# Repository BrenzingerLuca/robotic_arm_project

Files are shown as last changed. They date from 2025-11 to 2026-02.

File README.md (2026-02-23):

# PI-Bot: Distributed 3-DOF Robotic Arm

## Table of Contents
1. [Project Overview & Demo](#1-project-overview--demo)
2. [System Architecture](#2-system-architecture)
3. [Key Features](#3-key-features)
4. [PI-Bot control center (GUI)](#4-gui)
5. [Digital Twin](#5-digital-twin)
6. [Hardware & Wiring](#6-hardware--wiring)
7. [Quick start](#7-quick--start)
8. [Challenges & Solutions](#8-challenges)

## Project Structure 

```text
robotic_arm_project/
├── docs/           
├── src/   
├──── move_it_services/         # Custom Srv/Msg definitions (e.g. MoveToXYZ)
├──── my_robot_interfaces/      # Custom interfaces used in multiple nodes
├──── pca9685_servo_controller/ # Control the physical servos 
├──── potentiometer_reader/     # Read out potentiometer values
├──── robot_controller/         # MoveIt2 controller config
├──── robot_description/        # URDF & meshes
├──── robot_fk/                 # Forward kinematic calculations
├──── robot_gui/                # Pibot GUI
├──── robot_moveit/             # MoveIt2 configuration & SRDF
└── README.md                   # Documentation
```

## 1. Project Overview & Demo 
<p align="center">
  Projekt Demo
</p>

### About the Project
The **PI-Bot** is a custom-engineered, 3D printed, 3-DOF robotic arm designed as a full-stack robotics project. It demonstrates the seamless integration of distributed software systems, real-time hardware interaction, and motion planning. 

**Core Motivation & Software Focus**
The primary goal of this project was to master the software stack, specifically to understand **MoveIt** and motion planning architectures from the ground up. To bridge the gap between theory and reality, I implemented the system using 3D-printed parts and budget-friendly servos. 

While this accessible hardware introduces some mechanical imprecision, it served its purpose as a verification platform for the software. Future iterations will focus on hardware refinement to improve physical accuracy, though the core of this project remains a deep dive into robotics software engineering.

The project covers:
*   **Mechanical Design in CAD:** 3-axis manipulator with gripper.
*   **Embedded Control:** Custom ROS2 nodes on a Raspberry Pi 4 for PWM actuation and ADC sensor readout.
*   **Advanced Middleware:** MoveIt2 for path planning and a synchronized Digital Twin.
*   **UI:** A PySide6/Qt GUI for orchestration.

---

## 2. System Architecture 

The PI-Bot is built on a **distributed ROS2 architecture**, separating high-level logic from hardware-near execution to ensure modularity and system stability.

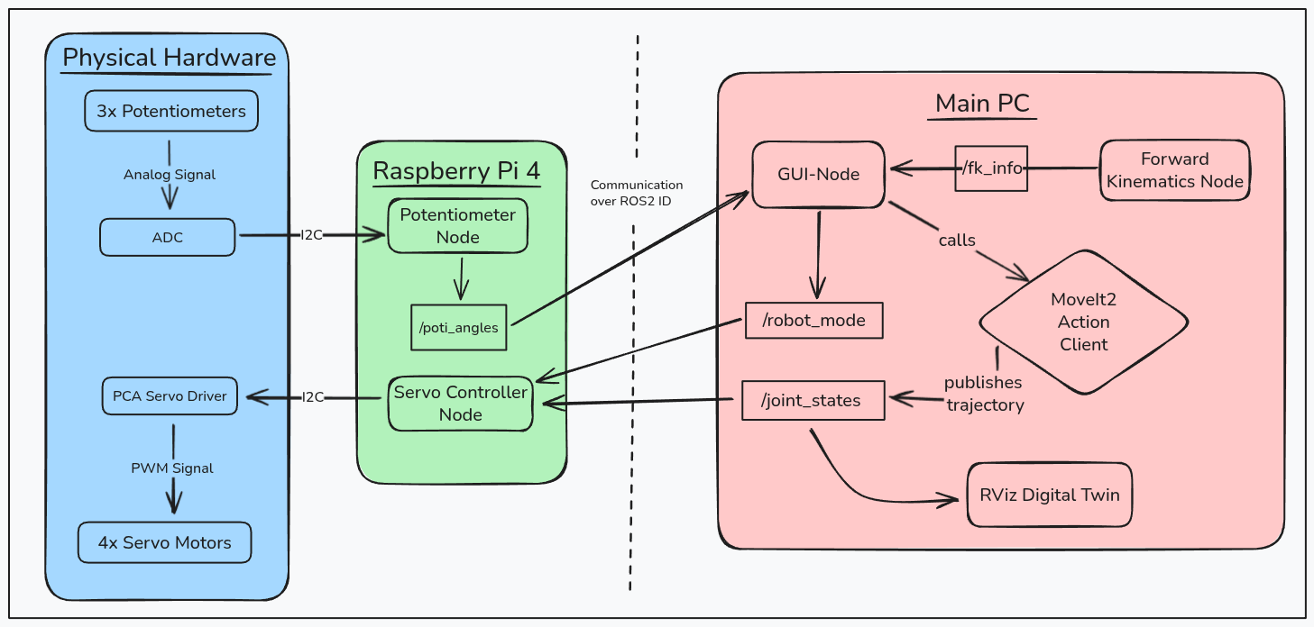
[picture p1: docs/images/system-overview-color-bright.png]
System Overview

*Figure: High-level overview of the distributed control loop and node communication.*

### Main PC (High-Level Logic)
The workstation acts as the "Brain" of the system, running computationally intensive nodes:
*   **GUI-Node (PySide6):** The central hub for user interaction. It subscribes to `/poti_angles` for manual input and `/fk_info` for real-time monitoring of the end-effector position. It orchestrates movements by calling the MoveIt2 Action Client and controls if the robot is in hardware or simulation mode.
*   **MoveIt2 Action Client:** Handles trajectory planning and inverse kinematics (IK). Once a path is planned, it publishes the trajectory points to the `/joint_states` topic.
*   **Forward Kinematics Node:** A dedicated node that processes joint angles to calculate the end-effector's XYZ position, providing feedback to the GUI.
*   **RViz Digital Twin:** Subscribes to `/joint_states` to provide a real-time 3D visualization of the robot's physical state.

### Raspberry Pi 4 (Hardware Abstraction Layer)
The Pi 4 serves as the bridge between the digital ROS2 environment and the physical hardware:
*   **Potentiometer Node:** Interfaces with the **ADS7830 ADC** via **I2C**. It reads analog signals from the three potentiometers, processes them, and publishes the values to the `/poti_angles` topic.
*   **Servo Controller Node:** Subscribes to the `/joint_states` and `/robot_mode` topics from the main PC and converts these states into **I2C** commands for the **PCA9685 Servo Driver**. When the robot is in hardware mode, the driver generates PWM signals to control the four servo motors.

### Communication Layer
*   **ROS2 Middleware:** All communication between the PC and the Raspberry Pi is handled over the local network using a shared **ROS_DOMAIN_ID**.
---

## 3. Key Features 

*   **Multi-Modal Hybrid Control:** The PI-Bot offers four distinct ways to interact with the hardware:
    *   **Joint-Space Control:** Precise manipulation of individual axes via interactive GUI sliders (0-180°).
    *   **Cartesian-Space Control:** Users can input target **XYZ-coordinates** (in mm). The system calls a custom `MoveToXYZ` service to plan and execute the motion.
    *   **Hardware-in-the-Loop (HIL):** Real-time physical **analog potentiometers** for intuitive manual positioning.
    *   **Interactive Planning (MoveIt2):** Full integration with RViz, allowing users to move the robot via **Drag & Drop (Interactive Markers)**. 

*   **Real-time State Sync:** The `sync_sliders_to_movement` logic continuously updates the GUI sliders to always match the actual hardware state, preventing jumps when switching control modes.
*   **Teach-In Sequence Recorder:** Store specific positions of the end-effector, or gripper in a table and execute them as a complex motion sequence.

*   **Asynchronous Processing:** Multi-threaded Python/Qt implementation to keep the UI responsive during long-running trajectory executions and service/action calls.

---
## 4. PI-Bot Control Center (GUI) 

The **PI-Bot Control Center** is a PySide6 (Qt)-based HMI providing centralized control, state monitoring, motion teaching, and direct servo manipulation via sliders.

<p align="center">
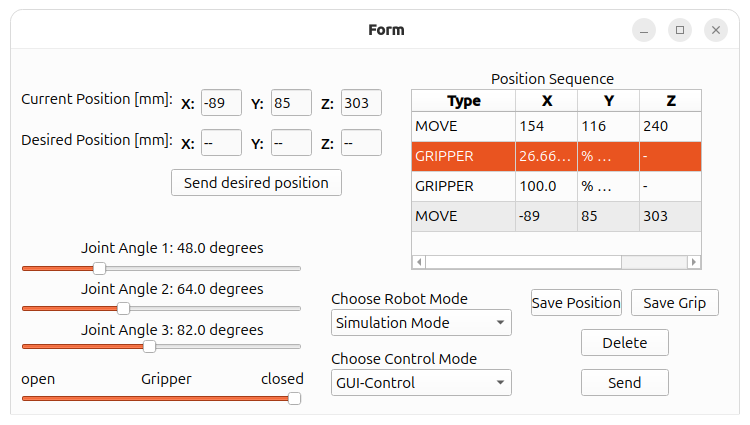
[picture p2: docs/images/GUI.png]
  
  <br>
  <em>Figure: The PI-Bot Control Center showing a programmed stacking sequence.</em>
</p>

## Core Interface Components

### Cartesian Monitoring & IK Control (Top Left)
- **Live Feedback:** Displays the end-effector’s real-time XYZ coordinates (mm), computed by the Forward Kinematics (FK) node.  
- **Target Input:** Users can enter desired Cartesian coordinates. Clicking **“Send desired position”** invokes MoveIt2 Inverse Kinematics (IK) to plan and execute the motion.

### Joint-Space Manipulation (Bottom Left)
- **Interactive Sliders:** Direct control of all three joints and the gripper.  
- **Bi-directional Sync:** Sliders continuously reflect the robot’s physical state, including movements from external potentiometers or those triggered by the “Send Desired Position” or “Sequence” functionality.

### Teach-In Panel (Right)
- **Sequence Recorder:**  
  - **“Save Position”** stores the current spatial position.  
  - **“Save Grip”** stores the current gripper state.  
- **Automation Workflow:**  
  - The table holds command types:  
    - `MOVE` → spatial target  
    - `GRIPPER` → aperture state  
- **Configuration:**  
  - Pressing **Delete** removes the currently selected (orange-highlighted) row.
- **Execution:**  
  - Pressing **“Send”** runs the sequence from top to bottom, enabling autonomous repetitive tasks (e.g., stacking or sorting).

### System Mode Management (Bottom Center)
- **Robot Mode:**  
  - **Simulation Mode** → Digital twin visualization  
  - **Hardware Mode** → Physical servo actuation  
- **Control Mode:**  
  - **GUI Control**  
  - **Potentiometer Control (Hardware-in-the-Loop)**
---
## 5. Digital Twin 

A core feature of the PI-Bot is the implementation of a **Digital Twin**. This virtual mirror ensures that every movement of the physical hardware is precisely reflected in the simulation environment (RViz) and vice versa.

<p align="center">
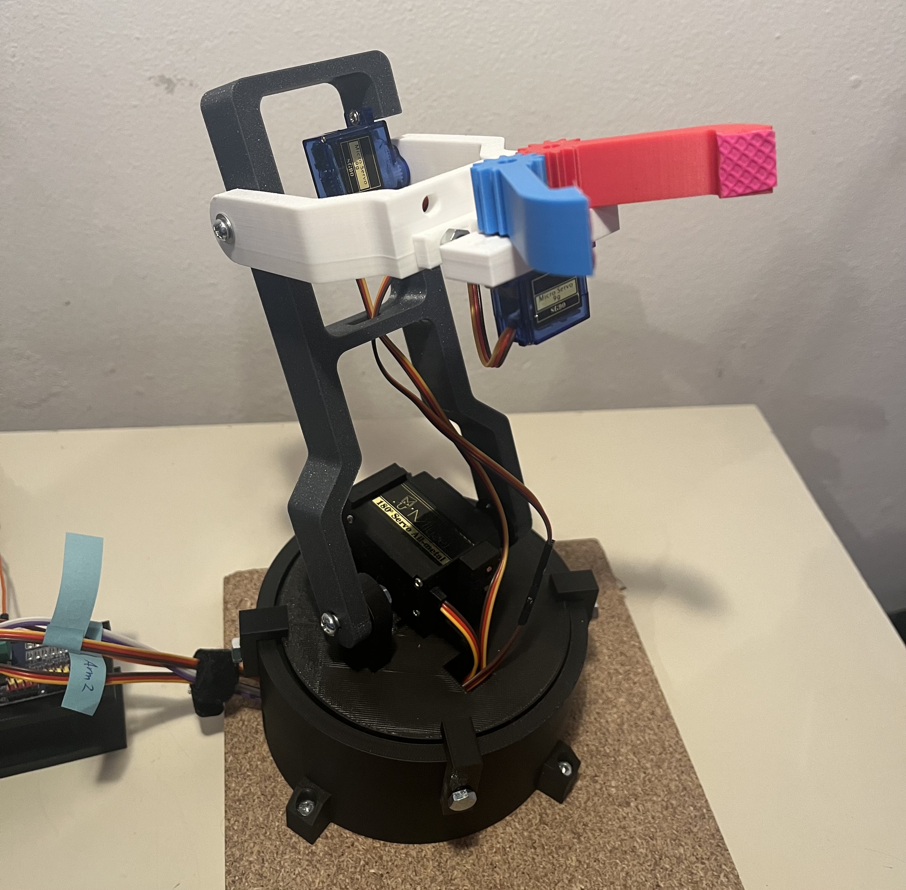
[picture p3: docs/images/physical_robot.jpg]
Physical PI-Bot
  
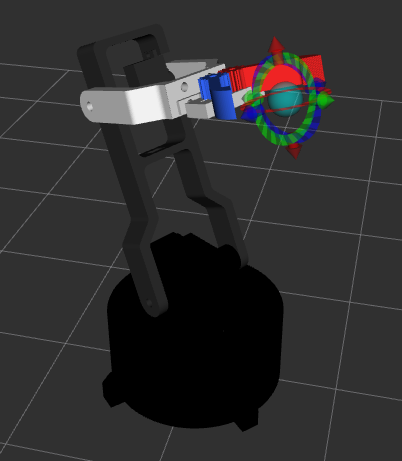
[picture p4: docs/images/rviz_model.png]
Digital Twin in RViz
  
  <br>
  <em>Figure: Comparison between the physical 3-DOF arm (left) and its synchronized Digital Twin in RViz (right).</em>
</p>

<p align="center">
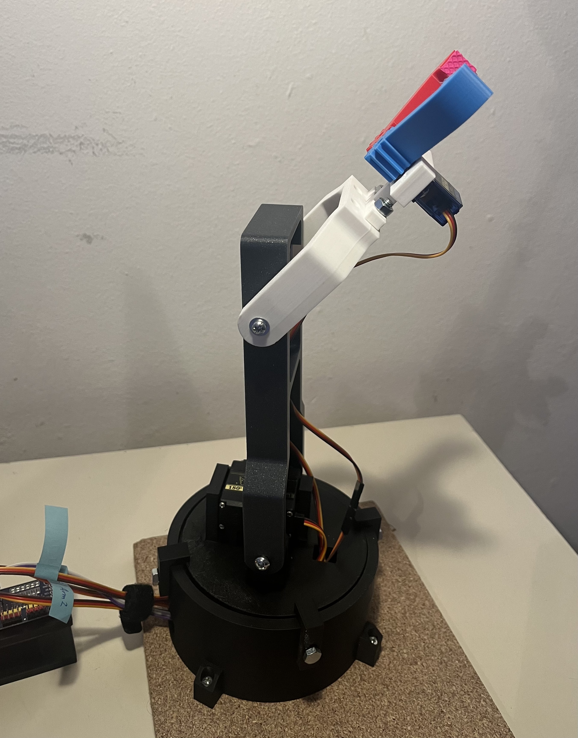
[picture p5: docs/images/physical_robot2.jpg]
Physical PI-Bot
  
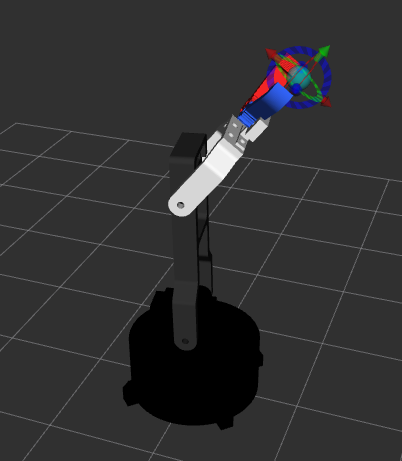
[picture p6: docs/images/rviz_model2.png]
Digital Twin in RViz
  
  <br>
  <em>Figure: Comparison between the physical 3-DOF arm (left) and its synchronized Digital Twin in RViz (right).</em>
</p>

### Physical-to-Digital Synchronization

*   **URDF & Mesh Integration:** The robot is defined via a custom **Unified Robot Description Format (URDF)**, using precise meshes from my own CAD Design and joint limits derived from the Moveit config.
*   **State Mirroring:** By subscribing to the `/joint_states` topic, the `robot_state_publisher` updates the **TF-tree** in real-time.
*   **Safety & Planning:** Before any physical movement occurs, MoveIt2 uses the Digital Twin to perform **collision checking** and trajectory validation, ensuring safe operation in the physical workspace.
*   **Remote Monitoring:** Through the distributed architecture, the Digital Twin allows for full remote monitoring of the robot's status over the network without needing a direct line of sight to the hardware.
---
## 6. Hardware & Wiring 

### Used Components:
| Component | Quantity | Interface | Description |
| :--- | :---: | :--- | :--- |
| **Raspberry Pi 4 (4GB)** | 1 | Network/I2C | Main distributed controller node |
| **ADS7830 ADC** | 1 | I2C (0x48) | 8-channel 8-bit ADC for potentiometer readout |
| **PCA9685 Driver** | 1 | I2C (0x40) | 16-channel PWM controller for servos |
| **MZ996 Servos** | 2 | PWM | High-torque servos for the base and the first arm|
| **9G Micro Servo** | 2 | PWM | Lightweight servo for the gripper mechanism and upper arm|
| **Potentiometers** | 3 | Analog | 10k Ohm linear potentiometers for HIL control |
| **Power Supply** | 1 | DC | External 5V/10A supply for Servo Driver |

### Wiring Diagram

<p align="center">
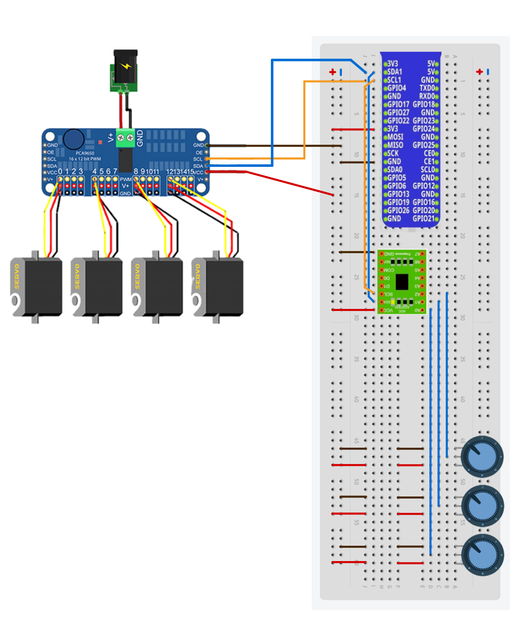
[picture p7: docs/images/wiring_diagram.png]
Visual Wiring Diagram
  
  <br>
  <em>Figure: Visual wiring overview.</em>
</p>

### Real-Life Implementation

<p align="center">
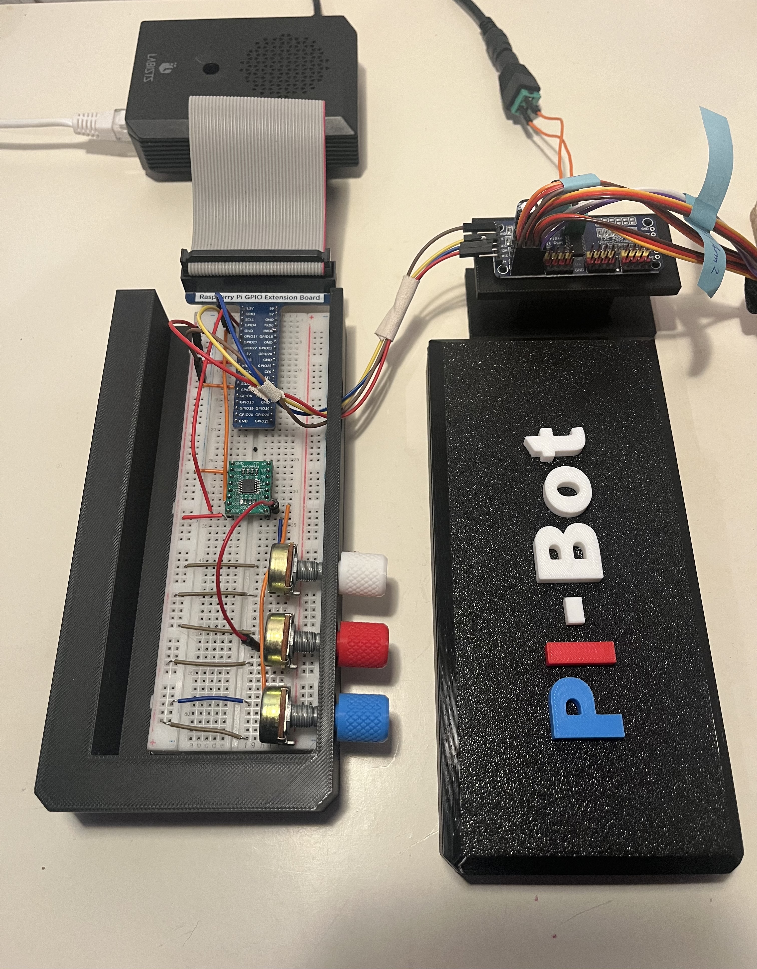
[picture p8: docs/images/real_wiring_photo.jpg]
Physical Wiring
  
  <br>
  <em>Figure: Physical hardware setup.</em>
</p>

### Schematic Diagram
<p align="center">
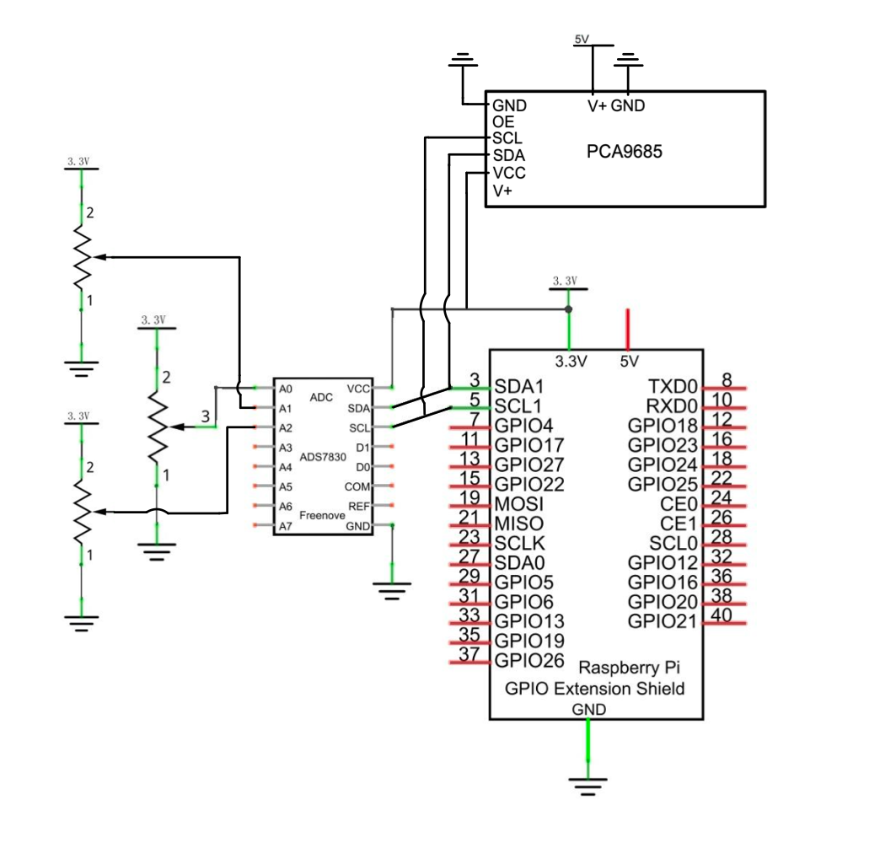
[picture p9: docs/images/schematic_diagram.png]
  
  <br>
  <em>Figure: Visual wiring schematic.</em>
</p>

### Implementation Details

*   **I2C Bus Management:** Both the **ADS7830** (ADC) and the **PCA9685** (PWM Driver) share the same I2C bus using unique hardware addresses (`0x48` and `0x40`). This keeps the wiring simple and modular.
*   **External Power Architecture:** The Raspberry Pi alone cannot provide enough current for four servos, especially during high-torque startup. I implemented an **external 5V/10A power supply** connected via the **PCA9685's power terminal**
*   **Sensor Precision:** The **ADS7830** provides 8-bit resolution (0–255). Mapping 255 steps to the 180° range of the servos results in a precision of **~0.7° per step**, which is more than sufficient for smooth manual manipulation via potentiometers.
*   **Signal Integrity & Motion Smoothing:** To mitigate signal noise and prevent mechanical jitter, I implemented an **Exponential Smoothing Filter (Low-pass)** within the Servo Controller node. This ensures fluid joint transitions and protects the hardware from abrupt accelerations.

## 7. Quick Start 

This project is developed and tested on **Ubuntu 24.04 (Noble Numbat)**.

- **Control Station (PC)** – Runs GUI, MoveIt 2, and the Digital Twin in RViz  
- **Robot Hardware (Raspberry Pi)** – Reading of the Potentiometers & controlling the servos

### Dependencies & Requirements 

- **OS:** Ubuntu 24.04 (Noble Numbat)
- **ROS 2 Jazzy:** Installed -> https://docs.ros.org/en/jazzy/Installation.html
- **Python-Version**: 3.12
- **Network:**  
  - Both devices must be in the **same network**  
  - `ROS_DOMAIN_ID` must **match on both machines**

Before setting up the workspace, you must install the ROS 2 build tools (`colcon`), the dependency manager (`rosdep`) and some python tools. 
```bash
# Install colcon, rosdep, and python tools
sudo apt update
sudo apt install python3-colcon-common-extensions python3-rosdep python3-pip -y
```

```bash
sudo rosdep init
rosdep update
```

### Main PC (GUI & Simulation)
The main PC can operate independently, allowing you to run the GUI, RViz, and MoveIt without connecting to the physical robot.
In this mode, no hardware interaction is available, but the robot model in RViz can still be fully controlled through the GUI and MoveIt for simulation and testing.

**1. Clone the repository**
```bash
git clone https://github.com/BrenzingerLuca/robotic_arm_project.git
cd robotic_arm_project
```
**2. Python Environment Setup**    

**Important**: Virtual environments often cause path conflicts between ROS 2 and PySide6. To ensure seamless library discovery and communication, install requirements globally using the --break-system-packages flag instead of a venv.

```bash
pip install -r requirements.txt --break-system-packages
```
**3. Install ROS 2 Dependencies**
```bash
# 1. Source the global ROS 2 installation
source /opt/ros/jazzy/setup.bash

# 2. Install project-specific dependencies
rosdep install --from-paths src --ignore-src -r -y
```

**4. Build and Source**
```bash
# Build the project
colcon build --symlink-install

# Source the local workspace
source install/setup.bash
```

**5. Launch**
```bash
ros2 launch robot_gui pibot_gui.launch.py
```
After launching, the robot displayed in RViz can be controlled using the GUI and MoveIt, enabling motion planning and visualization without requiring the physical hardware.
**Known issue:** On the first launch RViz might fail to update the robot's pose. If the sliders have no effect, restart the program (Ctrl+C and relaunch).

### Raspberri Pi (Hardware Controller)
This step is only required if the necessary hardware is available.
However, for completeness, the full startup procedure is documented below.

The steps are the same as for the Main-PC but the launch file is different.

**Launch**
```bash
ros2 launch pca9685_servo_controller raspi.launch.py
```

These packages provide access to the I²C bus (smbus2) and the PCA9685 PWM controller used for driving the servos.

**Note:** for  this to work the I2C-Bus has to be activated and needs to be accessible.

---
## 8. Challenges & Solutions 

Building the **PI-Bot** as a solo project involved several technical hurdles. Below are the key challenges encountered during development and the engineering decisions made to resolve them:

### Servo Jitter & System Stability
*   **Challenge:** Initial tests showed significant servo jitter and occasional system resets when moving multiple joints simultaneously.
*   **Solution:** 
    *   **Hardware:** Offloaded PWM generation to a dedicated **PCA9685 controller** to ensure stable timing independent of the Raspberry Pi's CPU load.
    *   **Power:** Implemented a separate **external 5V/10A power rail** for the servos to prevent voltage drops on the Pi's logic board during high-torque movements.
    *   **Software:** Integrated an **Exponential Smoothing filter** (digital low-pass) in the `ServoController` node to clean up noisy analog signals from the potentiometers.

### Seamless Control Mode Transitions
*   **Challenge:** When switching back to GUI control after using the physical potentiometers or running an automated sequence, the robot would "jump" abruptly to the last stored slider position.
*   **Solution:** Developed the `sync_sliders_to_movement` logic. This function continuously synchronizes the GUI slider positions with the actual hardware joint states. This ensures a **seamless handover** between different control modes, preventing sudden mechanical stress or dangerous movements.

### Responsive HMI (GUI) Integration
*   **Challenge:** ROS2 service calls and action goals are blocking by nature. Running them in the same thread as the GUI would cause the interface to freeze during trajectory planning or robot execution.
*   **Solution:** Integrated the ROS2 spin-loop **asynchronously** into the PySide6 event loop using a `QTimer`. By utilizing non-blocking **Action Clients** and `add_done_callback` functions, the GUI remains fully responsive and interactive while the PI-Bot is planning or executing complex trajectories.

---

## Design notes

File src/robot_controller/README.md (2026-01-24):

# robot_controller

This package configures and launches the **ros2_control** infrastructure for the robot. It does not contain application logic, but provides:

* Controller configuration (YAML)
* A launch file to start `ros2_control`, controllers, and state publishing

The package acts as the bridge between the robot description (URDF) and higher-level motion components such as MoveIt or custom controllers.

---

## Package Structure

```
robot_controller/
├── include/
├── src/
├── config/
│   └── robot_controllers.yaml
├── launch/
│   └── robot_controllers.launch.py
└── package.xml
└── CMakeList.txt
```

---

## Purpose of the Package

**Intent:**

* Start the ROS 2 control framework for the robot
* Load and configure controllers for arm joints and the gripper
* Publish joint states for visualization and downstream consumers

**Design assumptions:**

* The robot URDF is provided by the `robot_description` package
* Controllers are position-controlled
* This package is used both in simulation and on real hardware

---

## Launch File Overview

The launch file performs the following steps:

1. Generates the `robot_description` parameter by processing a XACRO file
2. Starts `robot_state_publisher`
3. Starts the `ros2_control_node` (controller manager)
4. Spawns the following controllers:

   * `joint_state_broadcaster`
   * `arm_controller`
   * `gripper_controller`

This ensures that controller startup order is correct and all required interfaces are available.

---

## Controller Configuration (`robot_controllers.yaml`)

### Controller Manager

```yaml
controller_manager:
  ros__parameters:
    update_rate: 10
```

* Sets the control loop update rate (Hz)
* Applies globally to all controllers

---

### Arm Controller

```yaml
arm_controller:
  ros__parameters:
    joints:
      - joint_1
      - joint_2
      - joint_3
```

* Uses a `JointTrajectoryController`
* Controls three arm joints
* Operates in **position control mode**

```yaml
    open_loop_control: true
```

* Assumes the hardware executes commands without feedback correction
* Typical for simple servo or simulation setups

---

### Gripper Controller

```yaml
gripper_controller:
  ros__parameters:
    joint: gripper
```

* Uses a `GripperActionController`
* Accepts position commands via ROS action interface
* Intended for simple open/close behavior

---

### Joint State Broadcaster

```yaml
joint_state_broadcaster:
  type: joint_state_broadcaster/JointStateBroadcaster
```

* Publishes `/joint_states`
* Required for RViz, robot_state_publisher, and MoveIt

---

## Typical Usage

```bash
ros2 launch robot_controller robot_controllers.launch.py
```

This launch file is usually started:

* before MoveIt
* before hardware interface nodes
* as part of a larger system launch

---

## Summary

* `robot_controller` configures **ros2_control** for the robot
* Contains no motion logic, only configuration and startup
* Defines controllers for:

  * arm joints
  * gripper
  * joint state publishing
* Acts as a core infrastructure package in the robot software stack

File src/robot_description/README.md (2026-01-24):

# robot_description Package

## Overview

The `robot_description` package contains the complete **kinematic, visual, and control description** of the robot. It is the single source of truth for:

* Robot geometry (meshes)
* Kinematic structure (URDF)
* ros2_control integration
* RViz visualization setup

This package is intended to be reused by visualization, control, and planning components like MoveIt later on.

---

## Package Structure

```
robot_description/
├── launch/
│   └── display.launch.py
│   └── gazebo.launch.py (Comming soon.)
├── meshes/
│   └── *.stl
├── rviz/
│   └── display.rviz
└── urdf/
    ├── robot.urdf.xacro
    └── robot_ros2_control.xacro
    └── robot_gazebo.xacro (Comming soon.)
```

---

## URDF / XACRO Files

### robot.urdf.xacro

This file defines the **physical and kinematic structure** of the robot:

* All robot links and joints
* Joint limits, axes, and origins
* Visual meshes and inertial properties
* End-effector (`ee_link`) definition
* Mimic joint for the gripper

The robot consists of:

* A fixed `world` frame
* A 3-DOF revolute arm (`joint_1`, `joint_2`, `joint_3`)
* A two-finger gripper using a mimic joint (`gripper`, `gripper2`)

All joint names are consistent with:

* `/joint_states`
* ros2_control
* GUI and hardware interfaces

### robot_ros2_control.xacro

This file contains the **ros2_control configuration** and is included by `robot.urdf.xacro`.

Key aspects:

* Uses `mock_components/GenericSystem` as hardware interface
* Designed for simulation and visualization without real hardware
* Defines command and state interfaces for each joint
* Joint limits are aligned with URDF limits
* Gripper mimic behavior is mirrored in ros2_control

> Gazebo or real hardware plugins are **not yet included** and are planned as future work.

---

## Meshes

The `meshes/` directory contains all STL files referenced by the URDF:

* Base
* Arm segments
* Gripper components

Meshes are scaled uniformly (`0.01`) to match the URDF coordinate system.

---

## RViz Configuration

### rviz/display.rviz

This file provides a preconfigured RViz setup including:

* RobotModel display
* TF visualization
* Fixed frame set to `world`

It allows immediate visualization of the robot when launched.

---

## Launch File

### display.launch.py

This launch file starts the complete **visualization stack**:

* Loads the robot description via XACRO
* Publishes TF using `robot_state_publisher`
* Starts the GUI node
* Launches RViz with a predefined configuration

It is intended for:

* Development
* Debugging
* Demonstrations

---

## Usage

```bash
ros2 launch robot_description display.launch.py
```

Optional custom URDF:

```bash
ros2 launch robot_description display.launch.py model:=/absolute/path/to/robot.urdf.xacro
```

---

## Future Work

The following components are intentionally not part of the current package:

* Gazebo simulation integration
* Real hardware ros2_control plugins for Gazebo
* Collision geometry optimization

These features are planned to be added in future development stages to be able to not just visualize but also simulate the robot.

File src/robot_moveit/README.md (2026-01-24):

# robot_moveit

## Overview

The `robot_moveit` package contains all MoveIt 2 related configuration files for the **PiBot** robotic arm. It defines how the robot is represented inside MoveIt, how motion planning is performed, and how planned trajectories are executed using ROS 2 controllers.

This package is intentionally **configuration-only**. It does not contain custom C++ or Python nodes. Instead, it provides YAML, SRDF, and launch files that integrate the robot with the MoveIt 2 framework.

---

## Package Structure

```
robot_moveit/
├── config/
│   ├── initial_positions.yaml
│   ├── joint_limits.yaml
│   ├── kinematics.yaml
│   ├── moveit_controllers.yaml
│   ├── pilz_cartesian.yaml
│   └── robot.srdf
│
├── launch/
│   └── moveit.launch.py
├── src/
├── include/
└── package.xml
└── CMakeLists.txt
```

---

## Configuration Files

### `initial_positions.yaml`

Defines the initial joint positions used by MoveIt when starting the system. These values represent a safe **home pose**.

```yaml
initial_position:
  joint_1: 0
  joint_2: 0
  joint_3: 0
  gripper: 0
```

---

### `joint_limits.yaml`

Defines velocity and acceleration limits for each joint. These limits are enforced during motion planning and execution.

Key parameters:

* `default_velocity_scaling_factor`
* `default_acceleration_scaling_factor`
* `Per-joint velocity and acceleration constraints`

These limits should match the physical capabilities of the real robot.

---

### `kinematics.yaml`

Configures the inverse kinematics (IK) solver for the robot arm.

* Uses the **KDL kinematics plugin**
* Optimized for position-only IK
* Defines solver resolution and timeout

```yaml
arm:
  kinematics_solver: kdl_kinematics_plugin/KDLKinematicsPlugin
  kinematics_solver_search_resolution: 0.005
  kinematics_solver_timeout: 0.1
  position_only_ik: true
```

---

### `moveit_controllers.yaml`

Connects MoveIt to the ROS 2 controllers responsible for executing trajectories.

Configured controllers:

* `arm_controller` (FollowJointTrajectory)
* `gripper_controller` (GripperCommand)

These names must exactly match the controllers defined in the `robot_controllers.yaml` file in the `robot_controller` package.

---

### `pilz_cartesian.yaml`

Defines Cartesian motion limits used by the **Pilz Industrial Motion Planner**.

This enables safe and constrained Cartesian motions such as linear moves.

---

### `robot.srdf`

The Semantic Robot Description Format (SRDF) defines:

* Planning groups (`arm`, `gripper`)
* End effector definition
* Named group states (e.g. `home`)
* Disabled self-collisions for adjacent links

The SRDF works together with the URDF from `robot_description`.

---

## Launch File

### `moveit.launch.py`

This launch file starts the full MoveIt environment:

* Loads the robot URDF and SRDF
* Starts the `move_group` node
* Launches RViz with a MoveIt-specific configuration

A launch argument `is_sim` is provided to enable simulated time. This allows future integration with Gazebo or other simulators without changing the MoveIt configuration.

Example:

```bash
ros2 launch robot_moveit moveit.launch.py
```

---

## Interaction with Other Packages

* **robot_description**

  * Provides the URDF and meshes

* **robot_controller**

  * Executes trajectories generated by MoveIt

* **robot_gui / custom nodes**

  * Can send goals to MoveIt via the `move_group` interface

---

## Future Extensions

The package is designed to be easily extended with:

* Gazebo simulation support
* Additional planning pipelines (e.g. Pilz, STOMP)
* Collision objects and planning scenes

---

## Summary

The `robot_moveit` package provides a clean and modular MoveIt 2 configuration for the PiBot robot. It separates planning, execution, and description concerns, follows ROS 2 best practices, and serves as a solid foundation for both simulation and real-world operation.

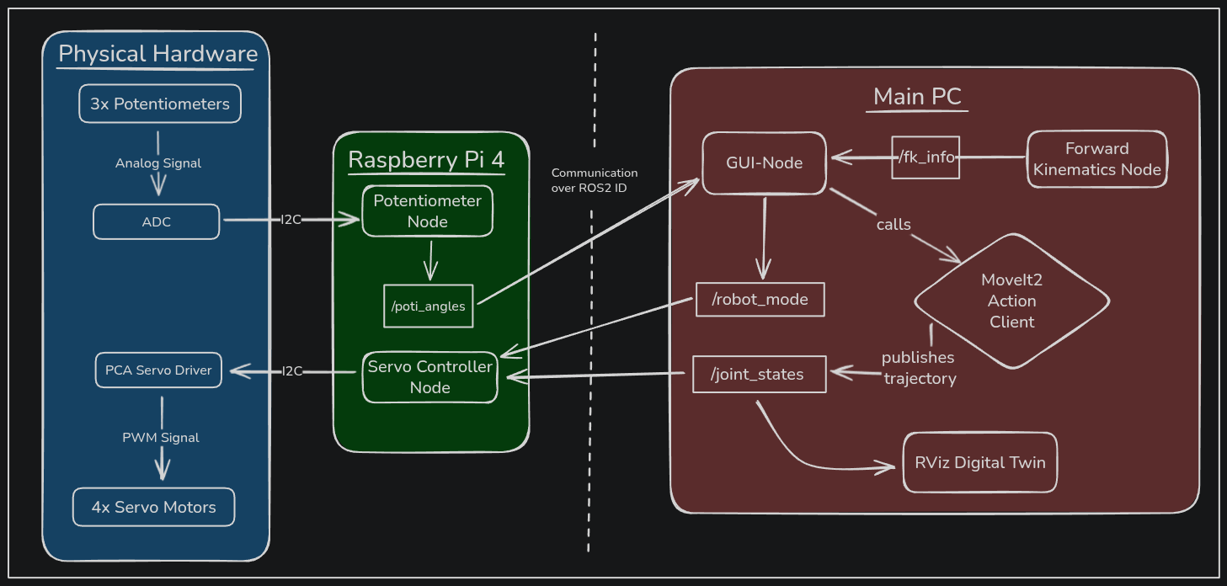
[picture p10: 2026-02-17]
docs/images/system-overview-color-dark.png

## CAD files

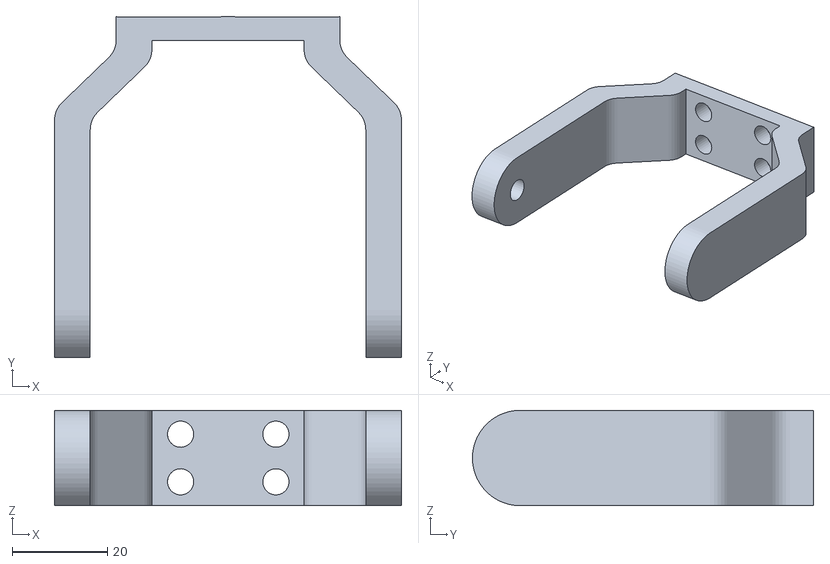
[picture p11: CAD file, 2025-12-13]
src/robot_description/meshes/SecondArm.stl
72.8 x 71.6 x 20.0

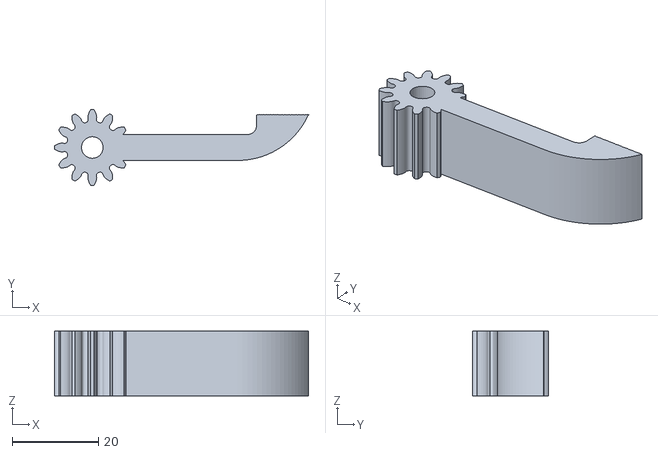
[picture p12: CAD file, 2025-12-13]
src/robot_description/meshes/GripperRightFinger.stl
58.7 x 17.5 x 15.0

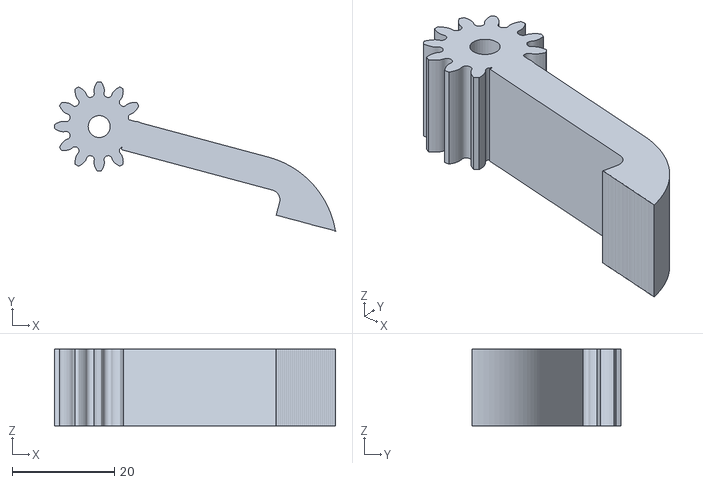
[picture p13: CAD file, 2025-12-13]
src/robot_description/meshes/GripperLeftFinger.stl
55.0 x 29.2 x 15.0

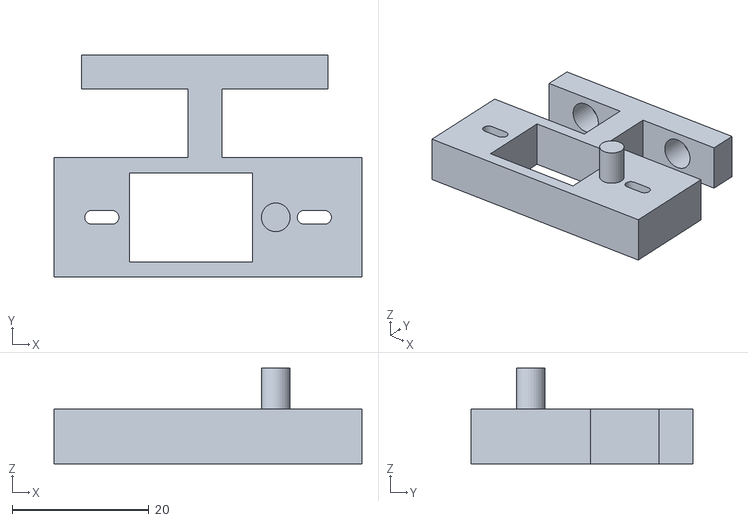
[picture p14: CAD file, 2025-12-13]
src/robot_description/meshes/GripperBase.stl
45.0 x 32.5 x 14.0

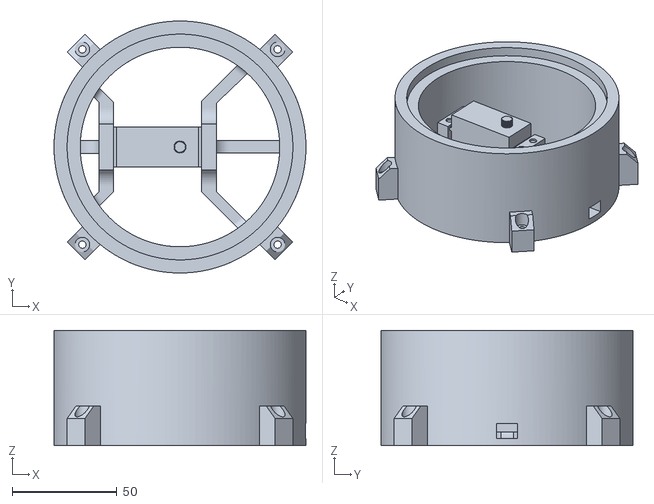
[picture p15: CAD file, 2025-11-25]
src/robot_description/meshes/Base_Bottom.stl
120.0 x 120.0 x 55.0

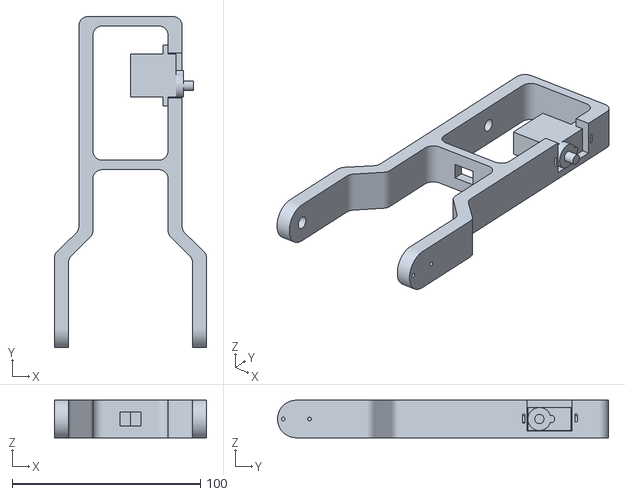
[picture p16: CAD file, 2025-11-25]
src/robot_description/meshes/Joint_1_with_Servo.stl
80.9 x 175.8 x 20.0

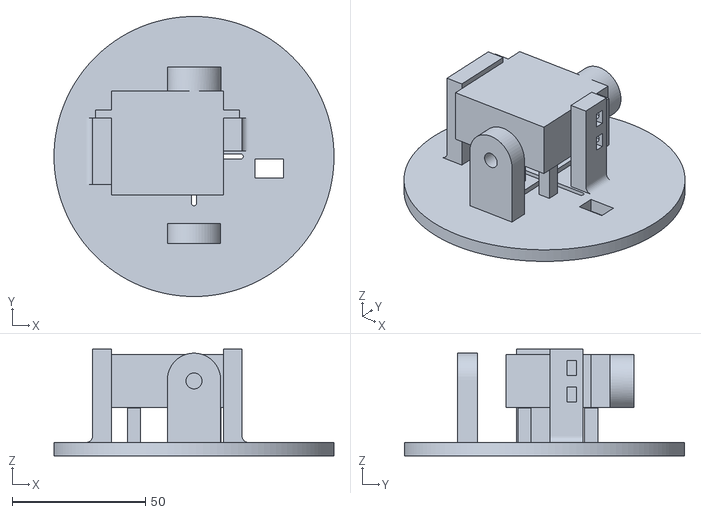
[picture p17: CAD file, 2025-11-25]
src/robot_description/meshes/Base_Plate_with_Servo.stl
105.0 x 105.0 x 40.0

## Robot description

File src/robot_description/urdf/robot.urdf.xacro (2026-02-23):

<?xml version="1.0"?>
<robot xmlns:xacro="https://www.ros.org/wiki/xacro" name="pibot">

    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
    <xacro:include filename="$(find robot_description)/urdf/robot_ros2_control.xacro"/>

    <xacro:property name="effort_big_servo" value="1.32" />
    <xacro:property name="velocity_big_servo" value="6.16" />
    <xacro:property name="PI" value="3.14159" />

    <link name="world"/>    

    <link name="base_link">
        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
        <inertial>
            <mass value="0.312"/>
            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
        </inertial>
    </link>
    
    <joint name="virtual_joint" type="fixed">
        <parent link="world"/>
        <child link="base_link"/>
        <origin rpy="0 0 0" xyz="0 0 0"/> 
    </joint>

    <link name="base_plate">
        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
        <inertial>
            <mass value="0.135"/>
            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
        </inertial>
    </link>
    
    <joint name="joint_1" type="revolute">
        <parent link="base_link"/>
        <child link="base_plate"/>
        <axis xyz="0 0 1"/>
        <origin rpy="0 0 0" xyz="0 0 0.5"/>
        <limit lower="-${PI/2}" upper="${PI/2}" effort="${effort_big_servo}" velocity="${velocity_big_servo}"/>
    </joint>

    <link name="first_arm">
        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
        <inertial>
            <mass value="0.070"/>
            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
        </inertial>
    </link>
    
    <joint name="joint_2" type="revolute">
        <parent link="base_plate"/>
        <child link="first_arm"/>
        <axis xyz="0 0 1"/>
        <origin rpy="${PI/2} 0 ${PI}" xyz="0 0.335 0.28"/>
        <limit lower="-${PI/2}" upper="${PI/2}" effort="${effort_big_servo}" velocity="${velocity_big_servo}"/>
    </joint>

    <link name="second_arm">
        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
        <inertial>
            <mass value="0.070"/>
            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
        </inertial>
    </link>

    <joint name="joint_3" type="revolute">
        <parent link="first_arm"/>
        <child link="second_arm"/>
        <axis xyz="0 0 1"/>
        <origin rpy="0 0 0" xyz="0 1.3 0"/>
        <limit lower="-${PI/2}" upper="${PI/2}" effort="${effort_big_servo}" velocity="${velocity_big_servo}"/>
    </joint>

    <link name="gripper_base">
        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
        <inertial>
            <mass value="0.070"/>
            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
        </inertial>
    </link>

    <joint name="joint_4_fixed_gripper" type="fixed">
        <parent link="second_arm"/>
        <child link="gripper_base"/>
        <origin rpy="0 0 0" xyz="-0.05 0.625 -0.33"/>
    </joint>

    <link name="ee_link">
        <inertial>
            <mass value="0.001"/>
            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
        </inertial>
    </link>

    <joint name="ee_fixed_joint" type="fixed">
        <parent link="gripper_base"/>
        <child link="ee_link"/>
        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
        <origin xyz="0 0.64 0.03" rpy="0 0 0"/>
    </joint>

    <link name="gripper_right">
        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
        <inertial>
            <mass value="0.070"/>
            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
        </inertial>
    </link>

    <joint name="gripper" type="revolute">
        <parent link="gripper_base"/>
        <child link="gripper_right"/>
        <axis xyz="0 0 1"/>
        <origin rpy="0 ${PI/2} 0" xyz="0 0.2 -0.05"/>
        <limit lower="-${PI/2}" upper="${PI/2}" effort="${effort_big_servo}" velocity="${velocity_big_servo}"/>
    </joint>

    <link name="gripper_left">
        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
        <inertial>
            <mass value="0.070"/>
            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
        </inertial>
    </link>

    <joint name="gripper2" type="revolute">
        <parent link="gripper_base"/>
        <child link="gripper_left"/>
        <axis xyz="0 0 1"/>
        <origin rpy="0 ${PI/2} 0" xyz="0 0.2 0.1"/>
        <limit lower="-${PI/2}" upper="${PI/2}" effort="${effort_big_servo}" velocity="${velocity_big_servo}"/>
        <mimic joint="gripper" multiplier="-1" offset="0"/>
    </joint>
</robot>

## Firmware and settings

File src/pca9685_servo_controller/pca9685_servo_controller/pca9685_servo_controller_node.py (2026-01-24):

import time
import math

# Imports needed for the Pi and the PCA
import board
import busio
from adafruit_pca9685 import PCA9685

# General ROS2 imports 
import rclpy
from rclpy.node import Node
from std_msgs.msg import String
from sensor_msgs.msg import JointState

class ServoController(Node):
    """
    ROS 2 node that maps JointState positions to PWM-controlled servos
    using a PCA9685 over I2C.

    Intent:
    - Act as a hardware bridge between ROS2 joint states and real servos
    - Allow switching between simulation and hardware mode at runtime in the GUI

    Assumptions:
    - Joint positions are published in radians, range [-pi/2, +pi/2]
    - Each joint corresponds to one servo
        - Gripper = Channel 0
        - Joint 1 = Channel 1
        - Joint 2 = Channel 2 
        - Joint 3 = Channel 3
    """
    
    def __init__(self, num_servos=4, freq=50):
        super().__init__('servo_controller')
        
        """
        WHY PCA9685 + Adafruit library:
        - Offloads PWM generation from the Raspberry Pi while also generating preciser PWM stopping the servos to jitter
        - Provides stable servo timing independent of OS load
        """
        i2c = busio.I2C(board.SCL, board.SDA)
        self.pca = PCA9685(i2c)
        self.pca.frequency = freq

        # Physical PCA9685 channels where servos are connected 
        self.pca_channels = [0, 1, 2, 3]

        """
        Robot mode handling:
        - Robot mode is published by the GUI to the /robot_mode topic when changed 
        - The robot mode is  set to simulation in the beginning for safety reasons
        - 'Simulation Mode' disables hardware output
        - Prevents accidental servo motion when starting 
        - A subscriber is created to update the mode when it's changed
        """
        self.robot_mode = "Simulation Mode"
        self.robot_mod_sub = self.create_subscription(String, 'robot_mode', self.update_robot_mode, 10)

        # Subscribe to joint_states to receive the desired joint positions
        self.create_subscription(JointState, 'joint_states', self.pot_callback, 10)
        self.num_servos = num_servos

        # Current servo angles (degrees), initialized to neutral position
        self.angles = [90.0] * self.num_servos
        self.goal_angles = self.angles

        """
        Motion smoothing parameter:
        - Limits how fast the servo moves toward the target
        - Reduces mechanical stress and jitter
        """
        self.max_step = 1.0 
        
        #Create a timer to update the servo position (50 Hz)
        self.create_timer(0.02, self.update)
        self.get_logger().info("Servo controller initialized")


    def pot_callback(self, msg):
        """
        JointState callback.

        Converts joint positions from radians to servo angles in degrees
        and stores them as target angles.

        Design choice:
        - Mapping [-pi/2, +pi/2] → [0°, 180°]
        - Matches common servo limits and the joint state values of the GUI and MoveIt node
        """
        num_positions = len(msg.position)

        for i in range(self.num_servos):
            if i < num_positions:
                rad = msg.position[i]
                deg = math.degrees(rad) + 90.0  # -pi/2 -> 0°, pi/2 -> 180°
                self.goal_angles[i] = deg
            else:
                # Defensive warning if joint_states is incomplete
                self.get_logger().warn(f"Only ({num_positions}) potentiometers are publishing for ({self.num_servos}) servos")
  
    def angle_to_raw12(self, angle):
        """
        Converts a servo angle (degrees) into a 12-bit PCA9685 PWM value.

        Assumptions:
        - Servo pulse range: 0.5 ms to 2.5 ms
        - PCA9685 uses 12-bit resolution (0-4095)
        """
        pulse_ms = 0.5 + (angle / 180.0) * 2.0
        fraction = pulse_ms / (1000.0 / self.pca.frequency)
        return max(0, min(int(fraction * 4095), 4095))

    def update(self):
        if self.robot_mode == "Simulation Mode":
            return
        
        for i in range(self.num_servos):
            # Gradual convergence toward target angle
            angle_diff = self.goal_angles[i] - self.angles[i]

            if abs(angle_diff) < self.max_step:
                self.angles[i] = self.goal_angles[i]
            # Smooth motion instead of hard step
            else:
                self.angles[i] += angle_diff * 0.2
        
            # Convert angle to PWM and send to hardware
            raw = self.angle_to_raw12(self.angles[i])
            self.pca.channels[self.pca_channels[i]].duty_cycle = raw << 4

    def update_robot_mode(self, msg):
        """
        Updates robot mode at runtime.

        WHY this exists:
        - To be able to switch the robot mode in the GUI 
        """
        self.robot_mode = msg.data
        if self.robot_mode == "Simulation Mode":
            self.get_logger().info("Robot Mode changed to Simulation Mode: Servo controll disabled")
        else:
            self.get_logger().info("Robot Mode changed to Hardware Mode: Servo controll enabled.")

def main(args=None):
    """
    Standard ROS 2 node lifecycle.

    Important cleanup:
    - PCA9685 is deinitialized explicitly to release I2C resources
    """
    rclpy.init(args=args)
    node = ServoController()
    try:
        rclpy.spin(node)
    except KeyboardInterrupt:
        pass
    finally:
        node.pca.deinit()
        node.destroy_node()
        rclpy.shutdown()

if __name__ == '__main__':
    main()

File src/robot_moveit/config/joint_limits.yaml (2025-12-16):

default_velocity_scaling_factor: 0.1
default_acceleration_scaling_factor: 0.1

joint_limits:
  joint_1:
    has_velocity_limits: true
    max_velocity: 10.0
    has_acceleration_limits: true
    max_acceleration: 8.0

  joint_2:
    has_velocity_limits: true
    max_velocity: 10.0
    has_acceleration_limits: true
    max_acceleration: 8.0

  joint_3:
    has_velocity_limits: true
    max_velocity: 10.0
    has_acceleration_limits: true
    max_acceleration: 8.0

  gripper:
    has_velocity_limits: true
    max_velocity: 10.0
    has_acceleration_limits: true
    max_acceleration: 8.0

  gripper2:
    has_velocity_limits: true
    max_velocity: 10.0
    has_acceleration_limits: true
    max_acceleration: 8.0

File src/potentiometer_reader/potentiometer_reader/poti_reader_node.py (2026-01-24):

import rclpy
from rclpy.node import Node
from std_msgs.msg import Float64MultiArray
import smbus2
import time
import math

class PotiPublisher(Node):
    """
    ROS 2 Node that reads analog values from an ADC via I2C 
    and publishes them as joint angles in radians.
    """
    def __init__(self):
        super().__init__('poti_publisher')

        # Publisher for the converted potentiometer angles
        self.publisher_ = self.create_publisher(Float64MultiArray, 'poti_angles', 10)
        
        # I2C Hardware Configuration
        try:
            self.bus = smbus2.SMBus(1) # Use I2C bus 1 (standard on Raspberry Pi)
            self.adc_address = 0x4b    # I2C address of the ADC chip
            # Control bytes to select channels 0, 1, and 2 on the ADC
            self.channel_bytes = [0x84, 0xC4, 0x94]
        except Exception as e:
            self.get_logger().error(f"I2C Fehler: {e}")

        # Timer to trigger the ADC reading loop at 10Hz (every 100ms)
        self.timer = self.create_timer(0.1, self.timer_callback) 
        self.get_logger().info("Potentiometer Reader Node started.")

    def read_channel(self, channel):
        """
        Reads a single raw byte from the specified ADC channel.
        :param channel: Index (0-2) corresponding to self.channel_bytes
        :return: Integer value (0-255) or None if communication fails
        """
        try:
            # Write the control byte to the ADC to select the channel
            self.bus.write_byte(self.adc_address, self.channel_bytes[channel])
            # Short delay for the ADC to process the request
            time.sleep(0.005)
            # Read the resulting 8-bit value
            return self.bus.read_byte(self.adc_address)
        except Exception as e:
            self.get_logger().error(f"I2C Read Error on channel {channel}: {e}")
            return None

    def timer_callback(self):
        """
        Main loop: reads all 3 channels, converts them to radians, 
        and publishes the result.
        """
        values = []
        for i in range(3):
            val = self.read_channel(i)
            if val is not None:
                # Convert 8-bit raw value (0-255) to radians (-pi/2 to pi/2)
                # Formula: (value / max) * range - offset
                rad = ((val / 255.0) * math.pi) - (math.pi / 2)
                values.append(rad)
        
        # Only publish if all three channels were read successfully
        if len(values) == 3:
            msg = Float64MultiArray()
            msg.data = values
            self.publisher_.publish(msg)
            # Optional: Log the angles for debugging
            # degrees = [round(math.degrees(a), 1) for a in values]
            # self.get_logger().info(f"Published Angles (deg): {degrees}")

def main():
    rclpy.init()
    node = PotiPublisher()
    rclpy.spin(node)
    rclpy.shutdown()

if __name__ == '__main__':
    main()

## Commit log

2025-10-23 First try to controll the servo
2025-10-23 Another try to controll the Servos this time using: python3-gpiozero
2025-10-26 Added a node that publishes the digitalised potentiometer values to control the servos
2025-11-02 Implemented a basic gui with 3 sliders that publish theire values as angles for every joint
2025-11-02 Made a new design with the QT Designer for the GUI. Also added logic to the 3 sliders so that they can controll the 3 servos of the robot later on.
2025-11-04 PCA controlling one servo and letting it oszillate with different velocities -working naxt step is to take published angles and controll 3 servos with the gui and the potentiometers
2025-11-13 Added a subscriper to the pca pkg that subscribes the potentiometer values so the servos can be controlled with the potentiometer- STILL NEEDS TO BE TESTED
2025-11-13 Servo Controll is working now with 3 servos and 3 potentiometers. I2C bus broke down so i had to reduce the data frequency. That caused the controll to be rather clunky so there needs to be improveme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
    [pca9685_servo_controller_node.py]
2025-11-14 Tested the servo controll via GUI Sliders and it worked perfectly next step is to implement hardware mode to be able to choose if the potentiometers or the sliders should controll the servos
2025-11-14 Controll state now fully implemented -possible improvement would be that the sliders follow the joints when in potentiometer mode to stop the robot from making very fast and uncontrolled movements wh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
2025-11-25 Visualize robot in RViz and Gazebo; update servo controller and potentiometer publisher to use radians
    - Added URDF-based robot visualization in RViz.
    - Integrated robot model into Gazebo for simulation (Gazebo actuation not yet implemented).
    - Utilized the `robot_state_publisher` package to publish joint states for visualization and communication with Rviz.
    - Created launch files for both RViz and Gazebo, which also start the custom robot GUI.
    - The robot GUI now allows switching between software and hardware control modes for RViz visualization.
    - Updated ServoController to accept joint positions in radians instead of degrees.
    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
    [Base_Bottom.stl, Base_Plate_with_Servo.stl, Joint_1_with_Servo.stl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]
2025-11-25 Changed the JointState names
2025-11-29 Complete URDF and RViz setup; implement Simulation and Hardware Modes; add robot FK package
    - Finished the URDF description of the robot.
    - Created a launch file to visualize the robot in RViz.
    - Implemented Simulation Mode and Hardware Mode:
    - Simulation Mode: only RViz visualization is updated.
    - Hardware Mode: both RViz and the real robot are actuated.
    - Added 'robot_fk' package to read the robot's forward kinematics using TF2.
2025-11-29 feat(gui): add subscriber to sync sliders during Pot Control mode
    Implemented a new JointState subscriber that updates the GUI sliders when
    Pot Control mode is active. This ensures a seamless transition between Pot
    Control and GUI Control by keeping the slider positions synchronized with
    the potentiometer inputs.
2025-12-02 Implementation of a 4th slider to controll the gripper. Also adapted the pca controll to control 4 instead of 3 Servos
2025-12-13 implementation of moveit
    [GripperBase.stl, GripperLeftFinger.stl, GripperRightFinger.stl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]
2025-12-13 Adapted the gui and the adc pub to the JointState names of moveit
2025-12-16 Implementation of the Sequence saving deleting and sending functionality in the GUI Window
    [joint_limits.yaml, robot.urdf.xacro]
2026-01-24 - Cleaned up the code + added detailed commenting for every pkg - Also added a main launch file to start the whole programm including the GUI with its full functionality and Moveit in just one Termin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
    [robot_controllers.yaml]
2026-01-24 - Added a launch file for the pkg's that needs to be startet on the MC / RasPi - Also added a potentiometer teleop pkg to replace the adc_pot_publisher pkg This pkg has improved control via Moveit in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
2026-01-24 - Addapted the pi launch file - Deleted the old adc pot pkg that was obsolete
2026-02-07 Initialize README with project details
    Added detailed project overview, system architecture, key features, hardware wiring, and project structure sections to README.
2026-02-07 Add system architecture diagram to README
    Added a mermaid diagram to illustrate the architecture of the system, including the Workstation and Raspberry Pi components.
2026-02-17 docs: finalize README and synchronize robot visualization Completed README structure (demo video pending) Updated Rviz model colors to match the physical PI-Bot hardware Added system diagrams and ass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
    [robot.urdf.xacro]
2026-02-17 COrrected small tipos
    Updated terminology for clarity and consistency, including changes to descriptions of potentiometers and power supply specifications.
2026-02-23 - Updating the Quickstart instructions because while testing PySide6 was not found by ros therefore break system installation is required
    - small change of starting pose of the robot
    [robot.urdf.xacro]
